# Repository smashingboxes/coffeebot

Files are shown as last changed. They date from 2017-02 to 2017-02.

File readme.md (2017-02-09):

# Coffeebot

Coffeebot is an internet connected coffee timer that lets your office know when coffee has been made. The project uses a Particle Photon processor to drive an LCD that contains the time that the last coffee was brewed and send events to Slack via [IFTTT](https://ifttt.com/). The hardware is basically an internet-connected LCD with four buttons, and can be used for many uses outside of coffee.

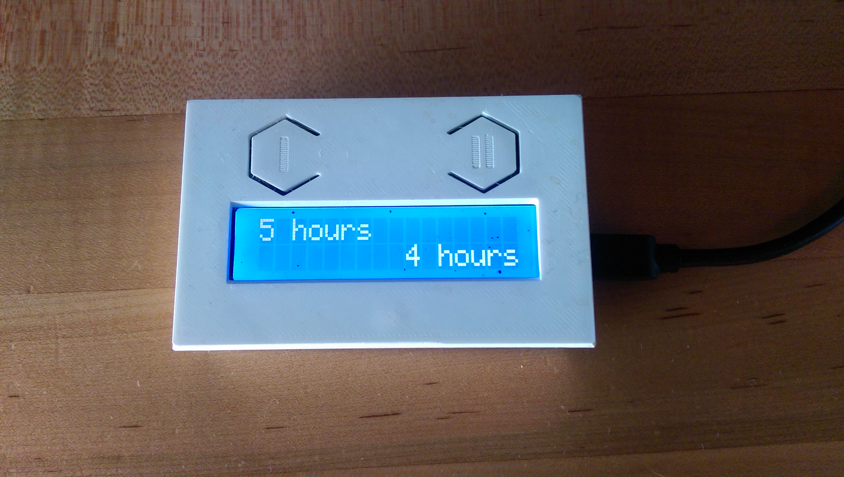
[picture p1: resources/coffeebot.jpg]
coffeebot picture


Full design and code files can be found in this repo and a direct link to buy the board from OSHPark can be found at: https://oshpark.com/shared_projects/5fzQkFQy

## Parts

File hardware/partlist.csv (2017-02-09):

Manufacturer | Part Number | Quantity |  | Description | Ordering Link
Panasonic | EVQ-Q2Y01W | 4 | S1, S2, S3, S4 | Pushbutton | http://www.mouser.com/Search/ProductDetail.aspx
Bournes | TC33X-2-103E | 1 | U$2 | Potentiometer | http://www.mouser.com/Search/ProductDetail.aspx
Vishay | CRCW1206330RFKEA | 1 | R1 | 330 Ohm Res. | http://www.mouser.com/Search/ProductDetail.aspx
Particle | Headerless Photon | 1 | U2 | Microcontroller | https://store.particle.io/
Newhaven Display | NHD-0216K1Z-NSW-BBW-L | 1 | LCD | LCD | http://www.mouser.com/Search/ProductDetail.aspx

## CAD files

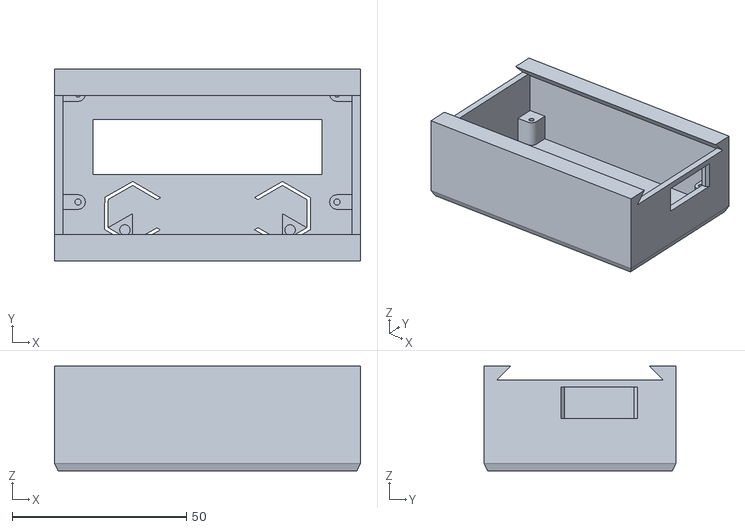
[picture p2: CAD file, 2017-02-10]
3d/coffeebot.stl
87.8 x 55.1 x 30.0

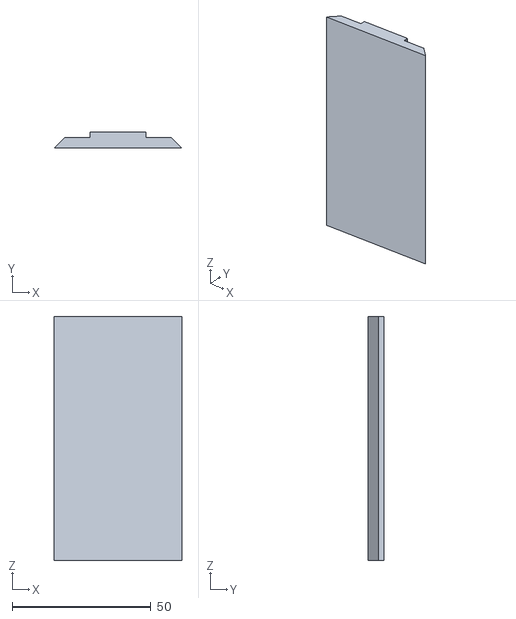
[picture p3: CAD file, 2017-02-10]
3d/coffeebot_back.stl
46.0 x 5.89 x 87.8

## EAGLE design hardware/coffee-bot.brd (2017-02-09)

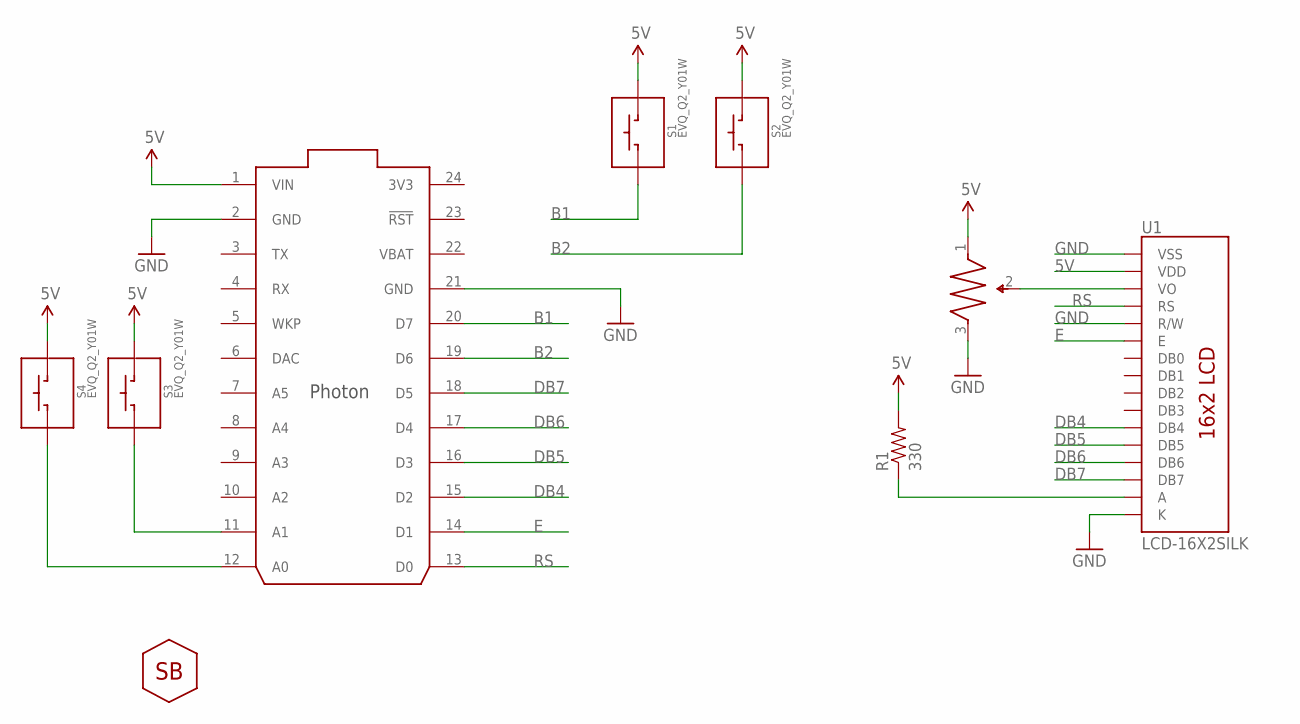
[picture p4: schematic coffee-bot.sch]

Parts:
R1: 330; 1206
S1, S2, S3, S4: EVQ_Q2_Y01W; EVQQ2
U1: LCD-16X2SILK; LCD-16X2
U2: PHOTON_SMD
U$2: TC-33X2
U$3: SBLOGO250MIL; SBLOGO

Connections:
3V3: U2.24 (3V3)
5V: R1.2, S1.B1 (B), S1.B2 (B), S2.B1 (B), S2.B2 (B), S3.B1 (B), S3.B2 (B), S4.B1 (B), S4.B2 (B), U1.2 (VDD), U2.1 (VIN), U$2.1
B1: S1.A1 (A), S1.A2 (A), U2.20 (D7)
B2: S2.A1 (A), S2.A2 (A), U2.19 (D6)
DB4: U1.11 (DB4), U2.15 (D2)
DB5: U1.12 (DB5), U2.16 (D3)
DB6: U1.13 (DB6), U2.17 (D4)
DB7: U1.14 (DB7), U2.18 (D5)
E: U1.6 (E), U2.14 (D1)
GND: U1.1 (VSS), U1.5 (R/W), U1.16 (K), U2.2 (GND), U2.21 (GND), U$2.3
unnamed: U1.3 (VO), U$2.2
unnamed: S4.A1 (A), S4.A2 (A), U2.12 (A0)
unnamed: S3.A1 (A), S3.A2 (A), U2.11 (A1)
unnamed: R1.1, U1.15 (A)
RS: U1.4 (RS), U2.13 (D0)
VBAT: U2.22 (VBAT)

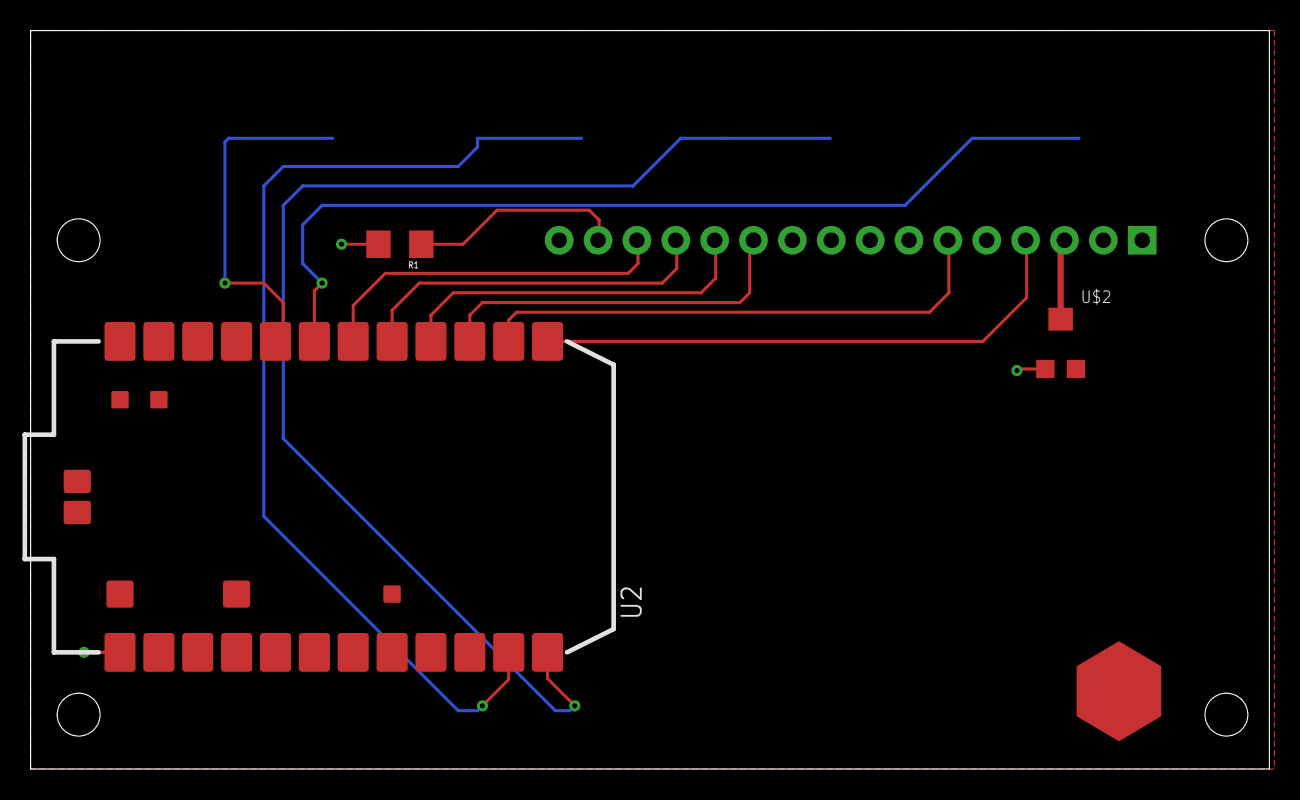
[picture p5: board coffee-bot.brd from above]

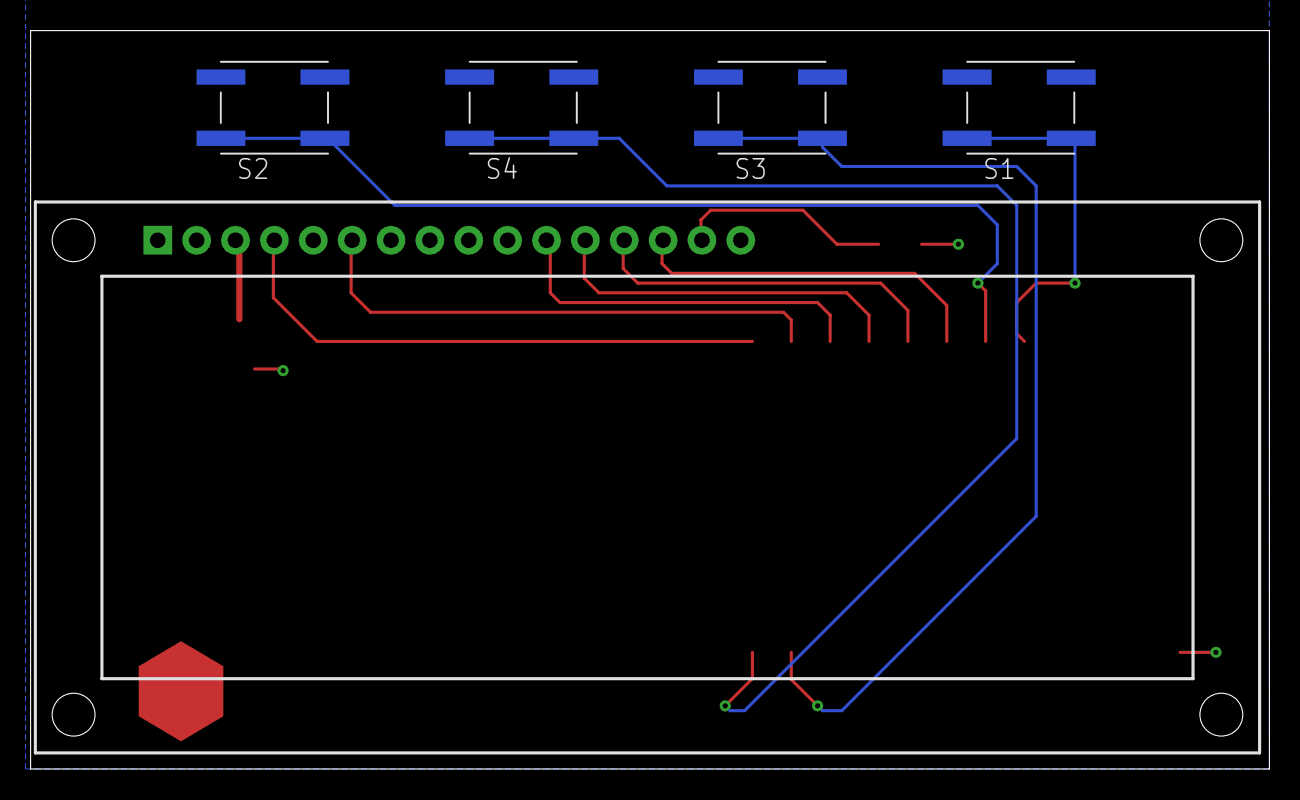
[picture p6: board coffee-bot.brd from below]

Board: 2 copper layers, 81.0 x 48.2 mm, 9 parts (5 on the bottom side), 14 nets.

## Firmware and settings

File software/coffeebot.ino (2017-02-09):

// This #include statement was automatically added by the Particle IDE.
#include "LiquidCrystal/LiquidCrystal.h"

LiquidCrystal lcd(D0, D1, D2, D3, D4, D5);

char row[17];

enum time_type_t {
  COFFEE_SECONDS,
  COFFEE_MINUTES,
  COFFEE_HOURS,
  COFFEE_DAYS
};

struct coffee_time_t {
  enum time_type_t type;
  int count;
};

void millis_to_time(struct coffee_time_t *time, int milliseconds) {
  int seconds = milliseconds / 1000;
  int minutes = seconds / 60;
  int hours = minutes / 60;
  int days = hours / 24;

  if(seconds < 60) {
    time->type = COFFEE_SECONDS;
    time->count = seconds;
    return;
  }

  if(minutes < 60) {
    time->type = COFFEE_MINUTES;
    time->count = minutes;
    return;
  }

  if(hours < 24) {
    time->type = COFFEE_HOURS;
    time->count = hours;
    return;
  }

  if(days > 999) days = 999;
  time->type = COFFEE_DAYS;
  time->count = days;
}

int format_diff(int milliseconds) {
  struct coffee_time_t time;
  char *plural_string;

  millis_to_time(&time, milliseconds);

  if(time.count == 1) {
    plural_string = "";
  } else {
    plural_string = "s";
  }

  switch(time.type) {
    case COFFEE_SECONDS:
      sprintf(row, "%i second%s", time.count, plural_string);
      break;

    case COFFEE_MINUTES:
      sprintf(row,  "%i minute%s", time.count, plural_string);
      break;

    case COFFEE_HOURS:
      sprintf(row,  "%i hour%s", time.count, plural_string);
      break;

    case COFFEE_DAYS:
      sprintf(row,  "%i day%s", time.count, plural_string);
      break;
  }

  return strlen(row);
}

int last_pressed_left;
int last_pressed_right;
int last_printed;

bool left_is_pressed;
bool right_is_pressed;

void setup() {
  lcd.begin(16,2);
  last_pressed_left = millis();
  last_pressed_right = millis();
  last_printed = last_pressed_left;

  // Left Button
  pinMode(D6, INPUT_PULLDOWN);
  left_is_pressed = false;

  // Right Button
  pinMode(D7, INPUT_PULLDOWN);
  right_is_pressed = false;
}

void loop() {
  int current_time = millis();
  int str_len;
  int i;

  if(digitalRead(D6) == HIGH) {
    if(left_is_pressed == false) {
      Spark.publish("pressed", "left");
      delay(50);
      last_pressed_left = current_time;
      left_is_pressed = true;
    }
  } else {
    left_is_pressed = false;
  }

  if(digitalRead(D7) == HIGH) {
    if(right_is_pressed == false) {
      Spark.publish("pressed", "right");
      delay(50);
      last_pressed_right = current_time;
      right_is_pressed = true;
    }
  } else {
    right_is_pressed = false;
  }

  if(current_time > (last_printed + 500)) {
    last_printed = current_time;
    lcd.home();

    str_len = format_diff(current_time - last_pressed_left);
    lcd.print(row);
    for(i = 0; i < (16 - str_len); i++) {
      lcd.print(" ");
    }

    lcd.setCursor(0, 1);
    str_len = format_diff(current_time - last_pressed_right);
    for(i = 0; i < (16 - str_len); i++) {
      lcd.print(" ");
    }
    lcd.print(row);
  }
}

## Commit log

2017-02-09 Initial commit.
    [coffee-bot.brd, coffee-bot.sch, partlist.csv]
2017-02-09 Fix 3D file extension.
    [coffeebot.stl]
2017-02-10 Updates coffeebot model and adds coffeebot back plate.
    [coffeebot.stl, coffeebot_back.stl]

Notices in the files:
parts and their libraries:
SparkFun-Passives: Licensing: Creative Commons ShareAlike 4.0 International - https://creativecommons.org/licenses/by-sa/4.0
